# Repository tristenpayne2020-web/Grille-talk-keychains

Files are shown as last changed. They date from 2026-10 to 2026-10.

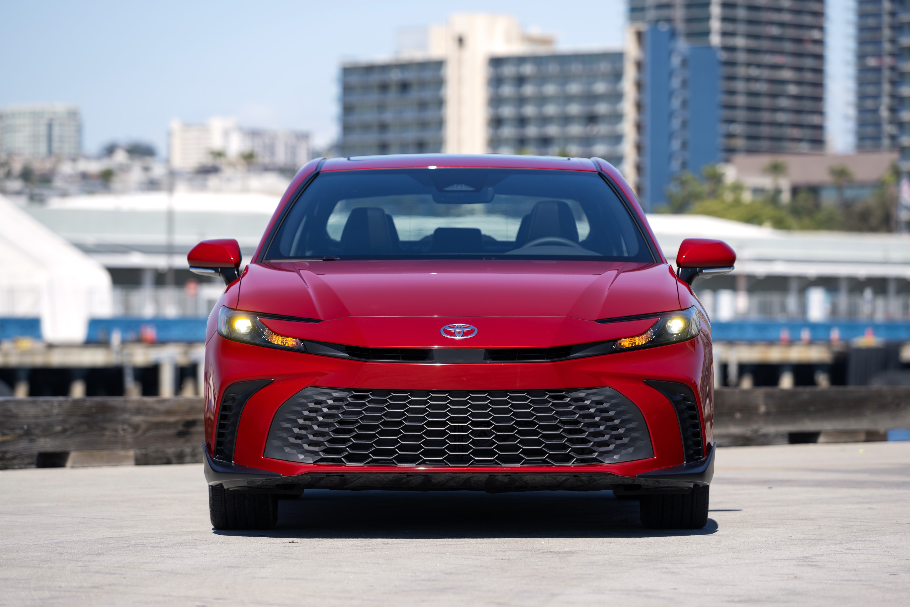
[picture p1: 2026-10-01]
kc/cars/camry_xv80/ref/front.jpg

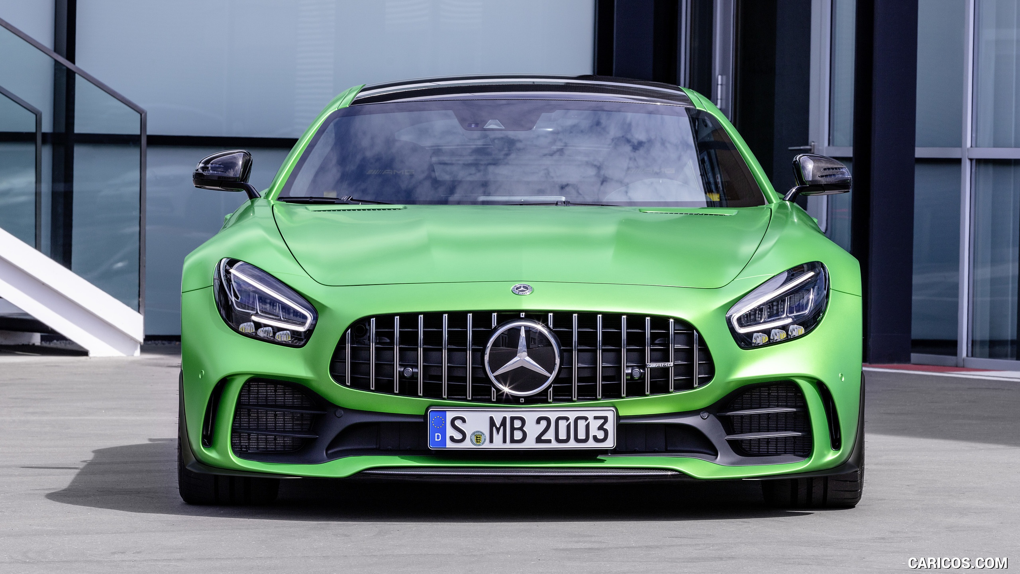
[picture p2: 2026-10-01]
kc/cars/amg_gt/ref/front.jpg

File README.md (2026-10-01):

# Grille Talk - car-front keychains

3D-printable car-front keychains in the style of the owner's BMW M3 G80 keychain, built for bulk printing on a
Creality K2 + CFS (0.4 nozzle) and sliced in Creality Print 7.3.

**Start here: [handoff.md](handoff.md)** - goal, current state, file map, what failed, next steps.

## Layout
- `kc/lib/` - pipeline (spec -> 2D maps -> 3D builds -> STL/STEP/3MF -> slice checks -> packaging)
- `kc/cars/<id>/spec.py` - one spec per car (`spec_APPROVED_by_user.py` = locked, user-approved design), `ref/` = reference photo
- `kc/style/` - the design-language references (the user's own G80)
- `kc/slicer_presets/` - Creality presets bundled so it runs without Creality Print installed, incl. the master preset
- `kc/queue_batch*.json` - cars waiting to be designed
- `workflows/car-keychains-next.js` - the multi-agent design workflow (trace -> critique -> revise -> art director)

## Run (from the repo root)
```
pip install -r requirements.txt
python kc/lib/export.py kc/cars/<id>/spec.py kc/cars/<id>/out --design-only   # fast 2D preview (face.png, overlay.png)
python kc/lib/export.py kc/cars/<id>/spec.py kc/cars/<id>/out --no-slice      # full build without the slicer
```
Slicing checks, `verify_plate2.py`, `finalize.py` (packaging into Downloads) and installing the master preset need the
user's Windows PC with Creality Print 7.3 (`CREALITY_EXE` env var overrides the slicer path).

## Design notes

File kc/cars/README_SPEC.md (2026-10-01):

# Car-front keychain spec guide (read fully before tracing)

The goal: a keychain for a new car that looks like it belongs to the same product line as the user's own
**BMW M3 (G80)** keychain. Study these first, they ARE the style guide:

| file (in `kc/style/`) | what it shows |
|---|---|
| `g80_reference_photo_the_user_traced.png` | the straight-on front photo the user traced in Fusion 360 |
| `g80_user_keychain_fusion_screenshot.png` | the user's finished keychain (their render) |
| `g80_user_keychain_iso.png` | same, isometric |
| `g80_face_flat.png` | the G80 rebuilt by this pipeline, flat face view (same renderer your car's `face.png` uses) |
| `g80_production_render.png` / `g80_classic_render.png` | the two 3D builds of the G80 |

Compare the photo with the keychain to see how the user abstracts a car: **what is kept, what is simplified, what is dropped.**

## Design language (measured from the G80)
1. **View and crop**: straight-on front elevation, perfectly mirror-symmetric. The outline is the body only: top edge =
   the base of the windshield / cowl (hood fully included, windshield/roof/mirrors/antenna excluded), sides = the
   fenders/wheel-arch flares, bottom = the front splitter/lip. **Tyres are not part of the outline.**
2. **Size**: the car body is always scaled to exactly **80.5 mm wide**; height follows the car (G80 = 38 mm). A low
   supercar will be flatter, which is correct. 3.0 mm thick (handled by the pipeline).
3. **Two colours only.** White = body paint. Black = everything dark: headlight units (the whole lens outline),
   grille openings, air intakes, splitter/lip, side air curtains/vents, prominent hood vents, badge.
4. **White on black** = the car's light signature (DRL graphics) drawn inside the black headlights. This is the most
   recognisable element of a modern car front - get its shape right (G80: the two hexagonal "L" strokes).
5. **Grille** = black region with a **relief pattern** matching the real car (G80: horizontal slats). Other patterns:
   vertical bars, honeycomb (`hex`), `grid`, `diamond`. Large intakes may also get a pattern if the real car has
   visible mesh/fins there.
6. **Engraved lines** (`groove`) for 2-6 key body lines only: hood shut line / hood edges / fender-to-A-pillar lines,
   creases (G80: hood outline + two fender lines). Width 0.5-0.6 mm.
7. **Small details**: parking sensors / washers as small rings (`ring`, outer r >= 0.9 mm, width 0.5 mm) - optional,
   max ~2 per side. Tow-hook covers, plates, text, wipers: dropped. Badge: simplified (see `badge`).
8. **Keyring tab**: on the viewer's LEFT side, at a height where the car edge is white (fender), usually 50-65 % of
   the height. Set `tab: {'y_frac': 0.55}` (fraction of height from the bottom) or `{'y_mm': 21}`.
9. **Printability (0.4 mm nozzle, hard rule)**: every black feature, white feature (e.g. a DRL stroke), groove and
   every gap between two features must be **>= 0.5 mm wide (0.6 preferred)**. Relief ribs and the gaps between them
   >= 0.6 mm (0.8+ looks better). The checker lists violations with their mm position; fix them in the spec. An
   auto-repair widens leftovers, but aim for **0 errors before repair**.
10. Simplify: use a few clean straight/curved segments like the G80 does, not noisy traced pixels. The G80 headlights
   are ~8 points each; the outline is ~40 points per half.

## Coordinate frame
Trace directly on the reference photo in **photo pixels** (`units: 'px'`). Calibration keys:
- `px_left`, `px_right`: x pixel of the car body's widest points (left/right body edge, NOT mirrors, NOT tyres)
- `center_x`: car centreline x pixel (default = midpoint of px_left/px_right; set it explicitly if the photo is off)
- `px_bottom`: y pixel of the lowest point of the outline (bottom of the splitter/lip)
- `y_scale` (optional, default 1.0): stretch heights if the photo is foreshortened. Keep 1.0 unless clearly needed.
The pipeline maps px -> mm (80.5 mm between px_left and px_right, y up, 0 at px_bottom).

Symmetry: trace ONE half. `outline_half` runs from the top of the centreline, outward, down the side, back to the
bottom of the centreline (either half works - it is mirrored). Every primitive is mirrored by default
(`mirror: True`); centred features (grille bridge, badge, centre intake) use `mirror: False` and must themselves be
symmetric about `center_x` (easiest: trace one half and keep mirror True - a shape crossing the centreline is fine,
it is unioned with its mirror).

## Spec file (`kc/cars/<id>/spec.py`)
```python
SPEC = dict(
    id='g87_m2', name='BMW M2 (G87)',
    ref='kc/cars/g87_m2/ref/front.jpg',           # path used for overlay.png (relative to scratchpad or absolute)
    units='px', px_left=112, px_right=1188, px_bottom=640, center_x=650,
    outline_half=[(650,180),(760,176),(930,196),(1080,236),(1150,300),(1188,420),(1180,560),(1120,625),(900,640),(650,640)],
    outline_smooth=0,                              # optional Chaikin smoothing passes for the outline
    prims=[                                        # painted IN ORDER, later paints over earlier
        dict(kind='poly', color='black', pts=[(...), ...]),                     # headlight unit
        dict(kind='stroke', color='white', width=0.7, pts=[(...), ...]),        # DRL stroke (width in mm)
        dict(kind='poly', color='black', pts=[...], relief=dict(type='hbars', pitch=2.4, rib=1.1)),   # grille
        dict(kind='poly', color='black', pts=[...], mirror=False),             # centre lower intake (symmetric)
        dict(kind='stroke', color='groove', width=0.55, pts=[...]),            # hood shut line
        dict(kind='ring', color='black', c=(x, y), r_mm=1.1, width=0.5),        # parking sensor
    ],
    badge=dict(type='roundel', c=(650, 330), d=4.0),   # c in px, d = diameter in mm
    tab=dict(y_frac=0.56),
)
```
Primitive kinds (coordinates in px unless noted; all widths/sizes in **mm**):
- `poly` pts [, smooth=n Chaikin passes, offset=+/-mm grow/shrink]
- `stroke` pts, width [, cap='round'|'flat'|'square', smooth=n]
- `circle` c, r (px) or r_mm ; `ring` c, r or r_mm (outer), width ; `ellipse` c, rx/ry (px) or rx_mm/ry_mm, rot (deg)
- colours: `black`, `white` (paints white over black - DRLs, grille bridge), `groove` (engraved line), `relief`
  (adds a pattern to an already-black area without repainting it)
- `relief` dict (mm): `type` hbars|vbars|bars|hex|grid|diamond|none, `pitch` centre spacing, `rib` rib width,
  `angle` deg, `offset` shift, `margin` gap between ribs and the recess wall (0 = ribs touch the wall).
  Good starting values: slats pitch 2.2-2.8 / rib 1.0-1.3 ; honeycomb pitch 2.2-2.6 / rib 0.7 ; grid pitch 2.4 / rib 0.7.
- `badge` types: `roundel` (BMW), `star` (Mercedes/AMG), `rings` (Audi; `ring_r`, `w`, `colour`), `shield` (Porsche/
  Lamborghini crest), `flags` (Corvette), `pony` (Mustang), `bar`. `d` = size in mm (>= 3.2). Badges can be
  switched off (`badge_on=False`), so never paint the badge into other primitives.

## Commands (run from the scratchpad dir `.../scratchpad`)
- Trace helpers: `python kc/lib/trace_tools.py grid|edges|points|mirror|rotate ...` (see its docstring; grid/edge
  labels are ORIGINAL photo pixels even on crops/zooms: `--crop x0 y0 x1 y1 --scale 3 --step 10`).
- Fast 2D iteration (1-2 s): `python kc/lib/export.py kc/cars/<id>/spec.py kc/cars/<id>/out --design-only`
  -> prints size + printability errors; writes `out/face.png` (flat keychain face) and `out/overlay.png` (your design
  painted back on the photo: red = outline, cyan = black edges, yellow = white edges). LOOK at both every iteration.
- Full build (~30-90 s): `python kc/lib/export.py kc/cars/<id>/spec.py kc/cars/<id>/out`
  -> both constructions (STL, STEP, 3MF single + full plate), 3D renders `out/production/*_render.png`,
  `out/classic/*_render.png`, and a real-slicer check (`build_report.json` -> `slicecheck`: `n_lost` must be 0 and
  `top_layer_coverage` >= 0.9 for all four parts).

## Badges without a built-in type (Nissan, McLaren, Dodge, Toyota, Cadillac, Chevrolet bowtie, Shelby...)
Draw a simplified badge as custom `geom`/`mm_poly` primitives (>= 0.5 mm strokes, 3.5-8 mm size) and put them behind a
module-level literal flag `SHOW_BADGE = True` (append them to `prims` only when True). Keep proportions faithful:
zoom in at print scale before accepting. See kc/cars/gt500_mustang/spec.py (COBRA_MM) for an example.

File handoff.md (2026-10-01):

# Handoff: Grille Talk car-front keychains

Project root: `C:\Users\trist\AppData\Local\Temp\claude\C--Users-trist\eb31f25f-c0e7-4c47-a2a2-d10d3da19ae7\scratchpad\kc`.
All paths below are relative to it unless absolute.

Delivery folder: `C:\Users\trist\Downloads\CarKeychains`. `finalize.py` wipes it and regenerates it.

Older running notes are in `RESUME_NOTES.md`. This file supersedes them where they disagree.

**Status: PAUSED by the user.** Do not start any work until the user says "continue". The user is close to their usage limit and wants work run in small batches.

---

## 1. The goal

The user runs a small business called **Grille Talk** that sells 3D-printed car-front keychains, through Etsy and at car meets.

They gave me their own BMW M3 G80 keychain (`C:\Users\trist\Downloads\G80Keychain.step`). I make more cars in the same design language, optimised for bulk printing on a **Creality K2 + CFS** with the **0.4 nozzle only**, using as little time and purge waste as possible, and sliced in **Creality Print**.

### Design language

- Straight-on front view, cropped at the windshield base, mirror-symmetric.
- Body 80.5 mm wide and 3.0 mm thick.
- White body, black details, white DRL light signatures.
- Relief grille, using slats or mesh.
- Engraved grooves 0.5–0.6 mm.
- Keyring tab on the viewer's left: 4.5 mm hole with a 2.0 mm wall.
- Minimum feature and gap size 0.5 mm.

### Builds produced for every car

- **Production "1-swap":**
  - black base 0–1.6 mm, white cap 1.6–3.0 mm;
  - one filament change per plate.
- **Classic:**
  - flush full-depth inlays like the G80;
  - about 15 changes per plate.
- **Custom body colour, 3 filaments:**
  - 1 = black, 2 = body colour, 3 = white for lights;
  - comes in production3 and classic3 versions;
  - about 8 and about 21 changes per plate respectively.

Each build is delivered as STL, STEP, a single 3MF and a full-plate 3MF (260×260 bed, prime tower in the back-right corner at 216/229). There are also renders, a sampler plate set, a pricing model (xlsx) and a pricing guide.

### User rules (all standing)

- **BMWs:** exactly ONE tow-hook cover, on the viewer's left, `mirror=False`. Never a mirrored pair.
- **Revision:** 2 rounds maximum.
- **Batches:** small pools of 2–3 cars, and pause when asked.
- **Approved designs are frozen:**
  - snapshot the specs when showing drafts (`spec_SHOWN_<stamp>.py`);
  - on approval, restore from that snapshot and lock it as `spec_APPROVED_by_user.py`;
  - running revise agents have overwritten approved designs before, so stop the workflow first.
- **Slicer settings:** ONE master preset, never per-car settings (see section 2).
- **NO LOGOS on any car.** The user decided this on 2026-09-30, for trademark reasons. It has not been implemented yet; see section 5.

---

## 2. Current state

### Finished and packaged: 28 cars

All of these are in `cars_pkg.json` and in Downloads, and all point at the master preset:

- g80_m3, g87_m2, f82_m4, gt3rs_992, c8_corvette, gt500_mustang, r8_audi
- svj_aventador, amg_gt, r35_gtr, g20_m340i_lci, camaro_zl1, mclaren_720s
- ct5v_blackwing, charger_srt, mk5_supra, challenger_hellcat, f92_m8, e30_m3
- f87_m2, amg_gt63_4door, c7_z06, g42_m240i_lci, lexus_is350, civic_11th
- camry_xv80, bugatti_chiron, lambo_urus

The user-approved specs are locked as `cars/<id>/spec_APPROVED_by_user.py`.

The G80 is built from `cars/g80_m3/spec_from_step.pkl` (made from the user's STEP by `cars/g80_m3/make_spec_from_step.py`, with the right tow ring dropped).

### Slicer: Creality Print 7.3.0.6149

The app auto-updated. It still installs to `C:\Program Files\Creality\Creality Print 7.1`.

- **CLI command:** `CrealityPrint.exe --cli --slice 1 --outputdir DIR --need-gcode-file in.3mf`, which writes `DIR/plate_1.gcode`.
- 7.3 slices real multi-colour 3MFs directly.

### Master preset (the single source of slicer settings)

- **Name:** `Grille Talk Keychain 0.20mm @Creality K2 0.4 nozzle`.
- **Parent:** `0.20mm Standard @Creality K2 0.4 nozzle` (setting_id GP004).
- **Installed at:** `%APPDATA%\Creality\Creality Print\7.3\user\3477890751\process\` (.json + .info).
- **Copies:** in `Downloads\CarKeychains\_MASTER_SLICER_PRESET\`, together with `HOW_TO_USE.txt`.
- **Contents:** the user's tuned Copy(2) process plus `k2config.KEYCHAIN`. The latest user changes are:
  - top_shell_layers 6
  - wall_transition_angle 50
  - ironing_flow 25%
  - ironing_spacing 0.12
- **Source of truth:** the installed preset file wins (`master_preset.settings()`), so edits the user saves in the GUI are picked up.
- **Changing a setting:** edit the preset, then run `python lib/apply_master.py "C:\Users\trist\Downloads\CarKeychains" cars/*/out`. That re-syncs every 3MF in seconds, with NO geometry rebuild. `finalize.py` also does this at its end.
- **Not verified in the GUI:** that the preset shows in the list, and that Ctrl+I imports a 3MF as geometry while keeping the per-part filaments. The user denied computer-use access to Creality Print.

### Verified numbers

From real 7.3 slices of the G80, 13-piece plate:

| Build | Time | Changes |
|---|---|---|
| 1-swap | 5h 12m | 1 |
| Classic | 8h 20m | 15 |
| Custom colour, 1-swap | 5h 34m | 8 |
| Custom colour, classic | 8h 15m | 21 |

Average cost is about $1.10 per keychain. Etsy at $16.99 with free shipping makes about $6.04 profit each; selling at a car meet for $10 makes about $8.65.

### Design workflow

The script is `C:\Users\trist\.claude\projects\C--Users-trist-AppData-Local-Temp-claude-C--Users-trist-eb31f25f-c0e7-4c47-a2a2-d10d3da19ae7-scratchpad\eb31f25f-c0e7-4c47-a2a2-d10d3da19ae7\workflows\scripts\car-keychains-next.js`. It runs these stages:

1. trace
2. two critics per round (likeness, and style + printability)
3. revise, repeated up to `max_rounds`
4. an art-director consistency pass over the new cars only

**Args:**
- `sp`, `pool`, `max_rounds`, `cars` (each `[{id, name, brief, prev}]`), `prev_done`;
- `others` = fixed reference spec paths, listing all finished cars except the G80.

The latest args file is `batchC_args.json`. The latest run, `wf_79ea1558-861` (GR86 + BRZ), was STOPPED by the user's pause while still tracing. Nothing in it completed, but partial files may exist in `cars/gr86` and `cars/brz_zd8`.

### Queues (not started)

- **`queue_batch6.json`:**
  - gr86, brz_zd8
  - g90_m5, f90_m5, ferrari_sf90, tesla_model3, tesla_models_plaid
  - jesko, ferrari_f40, huracan_evo, c6_corvette, c5_corvette
  - zonda_cinque was REMOVED by the user.
- **`queue_batch7.json`:**
  - g20_330i, lexus_lc500, g30_m550i, kia_stinger, s550_mustang
  - s650_mustang (reuses the old `cars/s650_mustang`)
  - audi_rs5, audi_rs7, nd_miata, camaro_1ss, ram_trx
  - trackhawk was REMOVED by the user (Jeep trade dress).
- **`queue_batch8.json`:**
  - dodge_viper, civic_type_r_fl5, f150, mini_cooper_s, elantra_n, silverado
  - escalade, x5m, x4m, macan, cayenne
  - jeep_wrangler: ASK the user before designing it, because the seven-slot grille is a trademark.
  - nissan_350z

  The queue_batch8 briefs already say there are no logos.

---

## 3. Files actively being edited or used

### lib/

- `k2config.py`:
  - builds the project config;
  - `KEYCHAIN` holds the overrides;
  - `build()` / `build_n()` apply the master preset and set `print_settings_id` to the master name and `inherits_group[0]` to the parent.
- `master_preset.py`: generates, installs and reads the master preset.
- `apply_master.py`: re-syncs project 3MFs to the master, without a rebuild.
- `verify_plate2.py`: real 7.3 slices of the delivered single and plate 3MFs, which produce `verify_report.json` (also read by the pricing script).
- `slicecheck.py`:
  - `slice_3mf()` uses the 7.3 syntax with a fallback;
  - `parse_gcode` interpolates G2/G3 arcs.
- `export.py`, `export3.py`, `build3d.py`, `geom.py`, `plate.py`, `render.py`, `package.py`, `write3mf*.py`, `cli_multi.py`, `lineup.py`, `trace_tools.py`.

### Top-level scripts

- `finalize.py`: packages Downloads. Steps:
  1. `package`
  2. lineup and gallery
  3. sampler
  4. pricing model and guide
  5. master preset install and HOW_TO
  6. `apply_master`
- `rebuild_all.py`: rebuilds and verifies every packaged car, then runs finalize. `finish_cars.py --only=id,id` does the same for selected cars.
  - Both log to `rebuild_log.txt` and `rebuild_status.json`.
- `add_cars_pkg.py <ids>`: adds finished cars to `cars_pkg.json`. Names come from `NAMES` or from the queue files.
- `make_sampler.py`, `make_readme.py`, `make_gallery.py`, `pricing_inputs.py`, `make_pricing.py`, `make_pricing_guide.py`.

### Specs and docs

- `cars/<id>/spec.py`: the car specs.
- `cars/README_SPEC.md`: the spec format guide.

### Per car, the finish sequence is

```
python lib/export.py cars/<id>/spec.py cars/<id>/out
python lib/export3.py cars/<id>/spec.py cars/<id>/out
python lib/verify_plate2.py cars/<id>/out
python add_cars_pkg.py <id>
python finalize.py
```

`finish_cars.py --only=<id>,...` runs this whole sequence.

---

## 4. Things that failed and what replaced them

- **Creality Print 7.1/7.2 CLI:**
  - It crashed without an embedded thumbnail. Always embed thumbnails.
  - It crashed on multi-colour 3MFs (prime-tower pre-check). The workaround was an STL route plus single-colour analytic estimates. This is now obsolete, because the 7.3 CLI slices multi-colour files directly.
- **Old CLI syntax:** `--slice 1 --export-3mf` stopped working in 7.3. Use the new syntax above.
- **Shapes in project_settings:** lists that don't match the GUI's 2-filament config crash the slicer. `k2config.conform()` fixes them against `lib/gui_2filament_config.json`.
- **`verify_plate2.py`:** it had a circular reference (`two_colour = cp` pointed at itself). Fixed by copying the dict.
- **STEP export:** a fuse with one shape returned null on the C8. Guarded with `if len(shapes)==1`.
- **G2/G3 arcs:** the checker drew them as chords, which falsely reported lost features on the GT3 RS. Fixed by interpolating the arcs.
- **Audi R8 badge:** the middle rings were classified as lights. Fixed by loosening the `split_white` thresholds (circ > 0.90, aspect < 1.2).
- **Workflow script:** a CRLF line ending caused a "control characters" error. Write the script with LF only.
- **`__SEE_FILE__` placeholder args:** these failed. Point the prompts at the state files instead.
- **Workflow stalls and session limits:** use small pools (2–3) and retry the trace once.
- **Approved specs overwritten by running revise agents:** stop the workflow FIRST, then restore from `spec_SHOWN_*` and check that it rebuilds pixel-identical. Discarded revisions go to `work/spec_revision_discarded*.py`.
- **Wipe tower in the master preset:** `wipe_tower_x` and `wipe_tower_y` aren't system process preset keys, so they were left out. The plate 3MFs keep their own tower position.
- **Windows paths in bash heredocs:** escaping problems. Use the Write tool or Python `os.path.join`.
- **The Civic "not a one-swap" report:** this was the user's own mistake. The Civic is fine, at 1 change.

---

## 5. Next steps, in order, once the user says "continue"

1. **No-logo versions of everything:**
   - Add one global switch (e.g. in `geom.badge_geoms` / `build_maps`, or an env/flag read by `export.py`) that drops every badge: the built-in types (roundel, star, rings, shield, flags, pony, bar) and the custom `SHOW_BADGE` badges.
   - Make it the default.
   - Run `python rebuild_all.py` (all 28 cars, about 2.5 min each), check that every car rebuilt and the logos are gone, then confirm finalize ran.
   - Tell the agents in all future design runs to make cars badge-free; the queue_batch8 briefs already say so.
2. **Snake-eye headlight variants** of the G80 M3 and G87 M2, as EXTRA versions next to the originals:
   - Get the exact headlight style or a reference photo from the user, or research it, before designing.
   - Use new ids, e.g. `g80_m3_snakeeye` and `g87_m2_snakeeye`, so the approved originals stay untouched.
3. **Resume the design runs:**
   - GR86 + BRZ: resume `wf_79ea1558-861` with `batchC_args.json`, or start fresh.
   - Then the rest of queue_batch6 in groups of 5: (g90_m5, f90_m5, ferrari_sf90, tesla_model3, tesla_models_plaid), then (jesko, ferrari_f40, huracan_evo, c6_corvette, c5_corvette).
   - Then queue_batch7, then queue_batch8. Ask about the Wrangler first.
   - Use pool 2–3 and 2 rounds. Add newly approved cars to `others`.
   - Show drafts as a contact sheet (reference | flat face | 3D render), as in `work/current_designs_*.png`, and snapshot the specs at show time.
   - When the user approves cars: stop the run, restore and lock the specs, then run `finish_cars.py --only=...`.
4. **Report back** to the user after each batch, with short updates.

---

## 6. Working from this repo (cloud session)

- The repo root plays the role of the old scratchpad: run every command from the repo root (`python kc/lib/...`), and pass
  the repo root as the workflow arg `sp` (`kc/batchC_args.json` has `<REPO_ROOT>` placeholders to replace).
- Install: `pip install -r requirements.txt` (Python 3.12+, cadquery 2.7 / OCP 7.8, vtk 9.3).
- No Creality Print in the cloud: use `--design-only` or `--no-slice`; `slicecheck`, `verify_plate2.py`, `rebuild_all.py`,
  `finish_cars.py`, `finalize.py` must run on the user's Windows PC (they slice with Creality Print 7.3 and write to Downloads).
  So in the cloud: design / trace / critique / build geometry; then on the PC: `git pull` + `python kc/finish_cars.py --only=...`.
- Presets: `kc/lib/k2config.py` and `master_preset.py` fall back to `kc/slicer_presets/` when the Creality AppData folders
  are missing. The installed preset on the PC stays the source of truth there; keep `kc/slicer_presets/<master>.json` in sync.
- Not in the repo (too big / regenerable): `kc/cars/*/out/` build outputs, agent scratch (`work/`, `cand/`), unused reference
  crops. Rebuild outputs with export.py. The G80 comes from `kc/cars/g80_m3/spec_from_step.pkl` (user STEP included as
  `G80Keychain_user_original.step`).
- The design workflow script is in `workflows/` (paths use `/`). In a Claude Code session the Workflow tool runs it via
  `scriptPath`; ultracode / explicit user opt-in is needed to launch workflows.

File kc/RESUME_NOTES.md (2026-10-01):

# Paused state (resume later)
- Packaged in Downloads\CarKeychains: 21 cars (cars_pkg.json).
- Approved-by-user specs are locked: cars/<id>/spec_APPROVED_by_user.py.
- Paused mid-batch (workflow stopped): c7_z06, g42_m240i_lci, lexus_is350, civic_11th, camry_xv80.
  Resume with car-keychains-batch4.js + batch5b_args.json (tracers reuse any partial files in their folders).
- Queued, not started (user: start later): queue_batch6.json (15 cars).
- After each batch: finalize (export, verify_plate, run_export3_all.py), add_cars_pkg.py <ids>, finalize.py.

## 2026-09-29 (after the Creality Print 7.3 update)
- Slicer settings the user asked for everything: top_shell_layers 6, wall_transition_angle 50, ironing_flow 25%, ironing_spacing 0.12 (lib/k2config.py KEYCHAIN).
- 7.3 CLI: CrealityPrint.exe --cli --slice 1 --outputdir DIR --need-gcode-file in.3mf -> DIR/plate_1.gcode (slices real multi-colour 3MFs). slicecheck.slice_3mf uses it.
- lib/verify_plate2.py = real slices of the delivered single/plate 3MFs (replaces verify_plate.py estimates).
- rebuild_all.py: rebuilds all packaged cars + NEW (c7_z06 g42_m240i_lci lexus_is350 civic_11th camry_xv80, user-approved and locked),
  checks the settings in the G-code, add_cars_pkg, finalize. Log rebuild_log.txt, status rebuild_status.json (--skip-done resumes).
- Design: batchB_args.json = queue_batch6 cars 1-5 (chiron, zonda, urus, gr86, brz), workflow run wf_bf72938e-c27, pool 3, 2 rounds.
  Next: batch6 cars 6-10 (g90_m5 f90_m5 ferrari_sf90 tesla_model3 tesla_models_plaid), 11-15 (jesko f40 huracan c6 c5), then queue_batch7.
  Snapshot specs to spec_SHOWN_<stamp>.py when showing drafts; lock approved ones as spec_APPROVED_by_user.py.
- USER: "don't change slicer settings per car - one master preset, I just add the geometry".
  lib/master_preset.py = ONE process preset "Grille Talk Keychain 0.20mm @Creality K2 0.4 nozzle" (inherits the K2 0.20mm Standard),
  installed in %APPDATA%\Creality\Creality Print\7.3\user\3477890751\process\ (+ copy & HOW_TO_USE in Downloads\CarKeychains\_MASTER_SLICER_PRESET).
  The installed preset is the source of truth (k2config.build reads it; GUI edits the user saves are picked up).
  Setting change from now on = edit the preset JSON (or user saves it in the GUI) + `python lib/apply_master.py <Downloads\CarKeychains> cars/*/out`
  (re-points / re-syncs every 3MF in seconds, no geometry rebuild). finalize.py does install + HOW_TO + apply_master at the end.
- USER removed the Pagani Zonda Cinque (stop work, drop from the list). cars/zonda_cinque left on disk, not packaged, removed from queue_batch6 + batchB_args.
- USER approved Bugatti Chiron + Lamborghini Urus exactly as shown in work/current_designs_20260929_155002.png -> run wf_bf72938e-c27 STOPPED,
  both restored from spec_SHOWN_20260929_155002.py (pixel-verified) and locked as spec_APPROVED_by_user.py (urus revision discarded ->
  work/spec_revision_discarded_lambo_urus.py). finish_cars.py --only=bugatti_chiron,lambo_urus builds/verifies/packages them.
- GR86 + BRZ: new run wf_79ea1558-861 (batchC_args.json, pool 2, 2 rounds). Next: g90_m5 f90_m5 ferrari_sf90 tesla_model3 tesla_models_plaid.
- PAUSED by the user at 16:35: GR86/BRZ run wf_79ea1558-861 stopped (resume with resumeFromRunId; completed agents are cached).
- TODO (user decision 2026-09-30, NOT started - wait until the user says continue): make NO-LOGO versions of EVERY car
  (user chose badge-free for all, trademark reasons). Add one global switch removing every badge (built-in badge types
  roundel/star/rings/shield/flags/pony/bar AND custom SHOW_BADGE badges), rebuild all packaged cars + re-verify + finalize.
  All future cars (queue_batch6/7) should be designed/packaged badge-free too (Jeep seven-slot grille = trade dress, note for Trackhawk).
- USER 2026-09-30: trackhawk REMOVED from queue_batch7. USER reports the Civic is NOT a one-swap in the slicer -> investigate + fix
  (check civic production 3MF part/filament assignment and colour changes per layer) when resuming. Do nothing until the user says continue.
- USER 2026-09-30: wants an EXTRA version of the G80 M3 and G87 M2 with aftermarket "snake eye" headlights (keep the originals too).
  Get the exact headlight style / reference photo from the user (or research) before designing. Not started.
- USER: Civic is fine (user error). queue_batch8.json = 12 new cars (viper, civic type R, F-150, Mini, Elantra N, Silverado, Escalade, X5M, X4M, Macan, Cayenne, Wrangler - Wrangler flagged: seven-slot grille trademark, ask first).

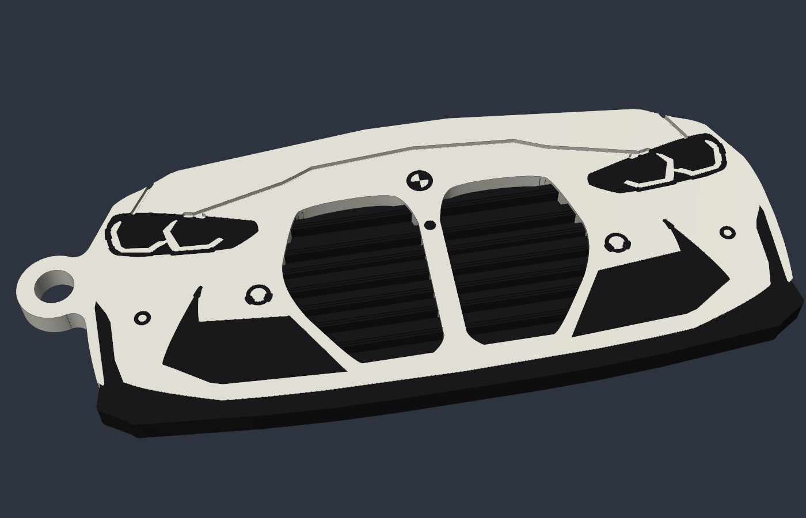
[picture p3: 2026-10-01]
kc/style/g80_classic_render.png

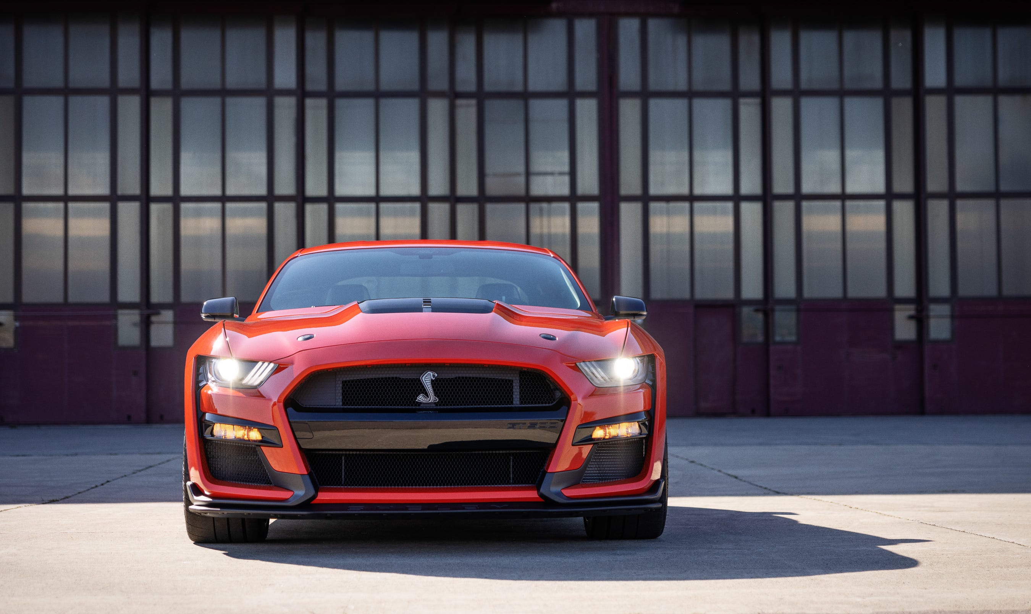
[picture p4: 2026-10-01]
kc/cars/gt500_mustang/ref/front_raw.jpg

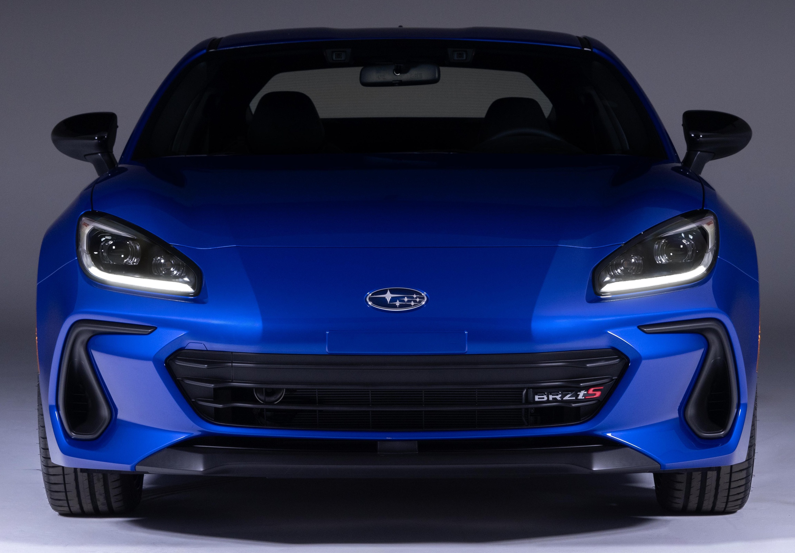
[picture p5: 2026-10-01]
kc/cars/brz_zd8/ref/front.jpg

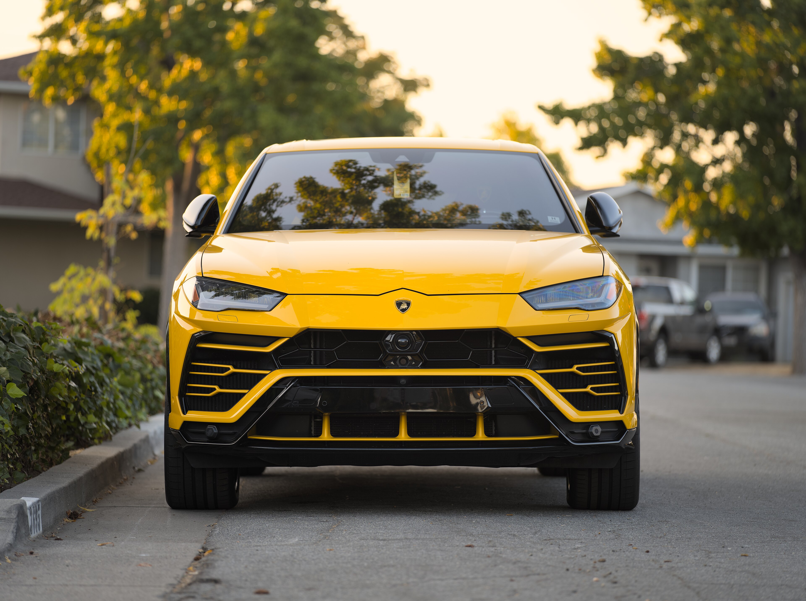
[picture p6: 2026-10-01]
kc/cars/lambo_urus/ref/dllu_3000.jpg

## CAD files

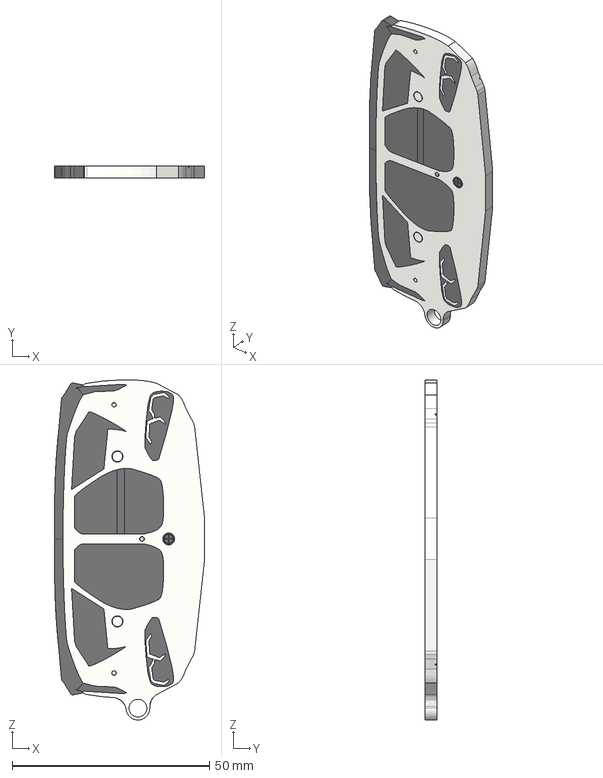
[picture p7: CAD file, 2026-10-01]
kc/cars/g80_m3/G80Keychain_user_original.step
38.0 x 3.00 x 86.1 mm

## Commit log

2026-10-01 Grille Talk car keychain pipeline: specs, references, presets, workflow, handoff
    28 finished cars (locked approved specs), queues for 38 more, master Creality preset,
    design workflow, and handoff notes for continuing in a cloud session.
    [G80Keychain_user_original.step, fdm_machine_common.json]
2026-10-01 Keep LF line endings (the workflow script fails with CRLF)
    [G80Keychain_user_original.step]
